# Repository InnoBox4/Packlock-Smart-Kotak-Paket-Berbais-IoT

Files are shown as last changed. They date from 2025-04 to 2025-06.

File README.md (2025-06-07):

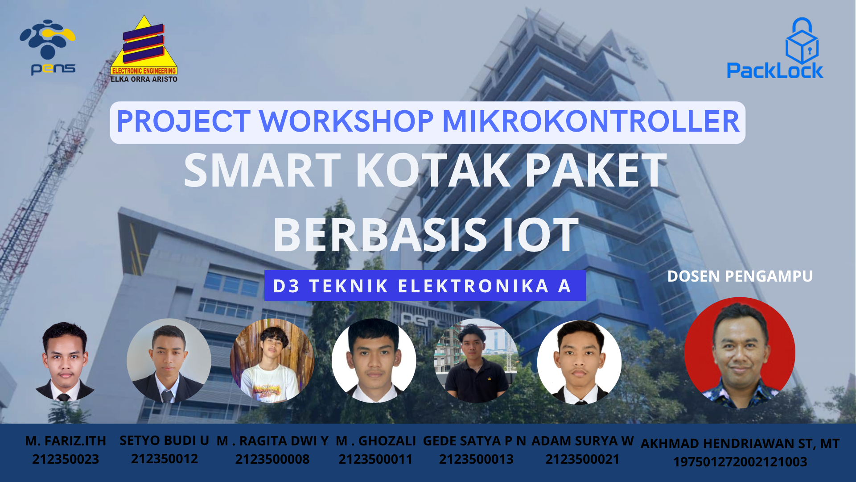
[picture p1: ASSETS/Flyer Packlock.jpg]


# Packlock
## Smart-Kotak-Paket-Berbasis-IoT

Proyek ini bertujuan untuk mengembangkan smart kotak paket berbasis IoT bernama PackLock, yang memungkinkan pengguna memantau status keberadaan paket secara real-time melalui dashboard web berbasis PHP. Sistem ini dirancang sebagai solusi pengiriman barang tanpa tatap muka yang aman dan efisien, terutama di era digital saat ini. PackLock dibangun menggunakan Arduino Uno sebagai mikrokontroler utama yang mengatur pembacaan sensor, kontrol aktuator, dan komunikasi data ke server lokal.

Untuk mendeteksi keberadaan paket, sistem menggunakan sensor infrared yang dipasang di dalam kotak. Selain itu, sensor ultrasonik dan reed switch digunakan untuk memantau status pintu depan dan pintu belakang kotak, apakah dalam keadaan tertutup atau terbuka. Ketika kondisi berubah, sistem akan mengirimkan data ke server melalui komunikasi serial dan hasilnya ditampilkan pada web secara real-time. Pengguna juga dapat menerima notifikasi dan melakukan kontrol jarak jauh melalui dashboard, termasuk membuka pintu kotak secara otomatis.

Web dashboard PackLock dibangun menggunakan PHP yang terhubung ke database untuk menyimpan dan menampilkan status terkini dari kotak paket. Dengan antarmuka yang sederhana, pengguna dapat dengan mudah mengetahui apakah terdapat paket di dalam kotak dan apakah pintu dalam keadaan tertutup atau terbuka. Sistem ini diharapkan dapat meningkatkan keamanan dan efisiensi dalam proses pengiriman dan pengambilan paket di lingkungan rumah atau perkantoran cerdas (smart building).

## Support By :
>- Dosen Pengampu : Akhmad Hendriawan ST., MT. (NIP.197501272002121003)
>- Mata kuliah : Workshop Mikrokontroller
>- Program Studi : D3 Teknik Elektronika
>- Politeknik Elektronika Negeri Surabaya<br>

## Team Member :
| NRP | Nama | Jobdesk |
| :---: | :---: | :---: |
| 2123500023 | Muhammad Fariz Ibnu T.H | Hardware Developer | 
| 2123500011 | M . Ghozali | Mekanik | 
| 2123500013 | Gede Satya Prawira Negara | Programer | 
| 2123500008 | M . Ragita Dwi Yuliansyah | Project Manager (PM) | 
| 2123500012 | Setyo Budi Utomo | Mekanik | 
| 2123500021 | Adam Surya Waskito | UI/UX Designer |

## Komponen Utama 
| Komponen | Fungsi | 
|---|---|
|Arduino Uno| pengontrol sistem |
| Ultrasonic Sensor HC-SR04  | deteksi pintu depan tertutup atau tidak | 
|Sensor Infrared (IR) Proximity FC-51 |deteksi paket masuk|
|Reed Switch + Magnet | deteksi pintu belakang terbuka/tertutup)|
|Servo Motor (SG90 / MG90S)|untuk membuka pintu|

## Flyer Packlock

Flyer Packlock

## Cara kerja Packlock

https://github.com/user-attachments/assets/c9181a2b-23b7-4780-8032-19ebb1beb945

## Iklan Produk Packlock

[Video Iklan Produk Packlock](https://youtube.com/shorts/VkG0_1tyrqw?feature=share)

## PPT Packlock

[PPT Packlock](https://www.canva.com/design/DAGpCFjL8s4/J2JU336eNsQ9mIj8pktKxA/edit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)

## Desain App di Figma

[Desain App Packlock di Figma](https://www.figma.com/design/fq3XM4EmNfqJVly56ajVYE/Packlock?node-id=0-1&t=N5Q5iODnZTlXCq0t-1)

## Desain 3D di Thingiverse 

[Desain 3D di Thingiverse](https://www.thingiverse.com/setyoo_io/collections/43256436/things)

## Simulasi Program di Wokwi

[Simulasi Program di Wokwi](https://wokwi.com/projects/429229658305672193)

## Video Simulasi Program

[Video Simulasi Program](https://github.com/user-attachments/assets/82a5f85e-70d9-47c1-b36e-2be93320dba2)

## Daftar Isi
- [Komponen Yang Digunakan](#Komponen-Yang-Digunakan)
- [Blok Diagram](#Blok-Diagram)
- [Diagram Arsitektur Sistem](#Diagram-Arsitektur-Sistem)
- [Hardware](#Hardware)
- [Desain UI UX](#Desain-UI-UX)
- [Desain 3D](#Desain-3D)
- [Desain Yang Sudah Jadi](#Desain-Yang-Sudah-Jadi)

## Komponen Yang Digunakan
1.Hardware
- Arduino Uno
- Motor Servo
- Sensor IR Obstacle
- Sensor Ultrasonik
- Conector Molex
- Shield PCB
- Kabel Jumper

2.Software
- Arduino IDE
- Visual Studio Code
- Kicad
- Inventor
- Figma
- Wokwi

3.Alat 
- Palu
- Meteran
- Gergaji
- Penggaris
- bulpoint
- Cutter
- Gunting
- Kuas
- Obeng
- Lem Tembak
- Solder 
  
4.Bahan
- Balok kayu Diameter 2 CM (5 Buah)
- Karton
- Paku Kecil
- Lem kayu
- Cat Kayu
- Paku Pines
- Cat putih
- Timah
- Solasi

## Desain Yang Sudah Jadi

Hasil Jadi

## Blok Diagram
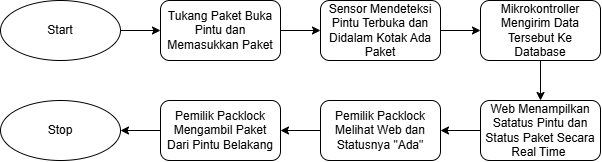
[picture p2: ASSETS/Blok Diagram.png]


## Diagram Arsitektur Sistem
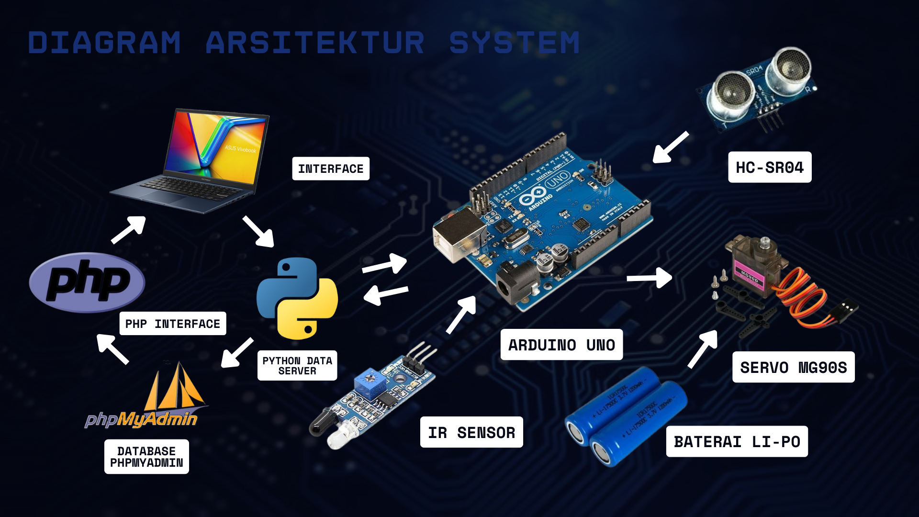
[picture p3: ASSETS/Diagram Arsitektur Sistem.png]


## [Hardware](https://github.com/InnoBox4/Packlock-Smart-Kotak-Paket-Berbais-IoT/tree/main/HARDWARE)

Berikut ini adalah hasil skematik dari rangkaian Smart Kotak Paket Berbasis IoT menggunakan software KiCad.
<div align="center">
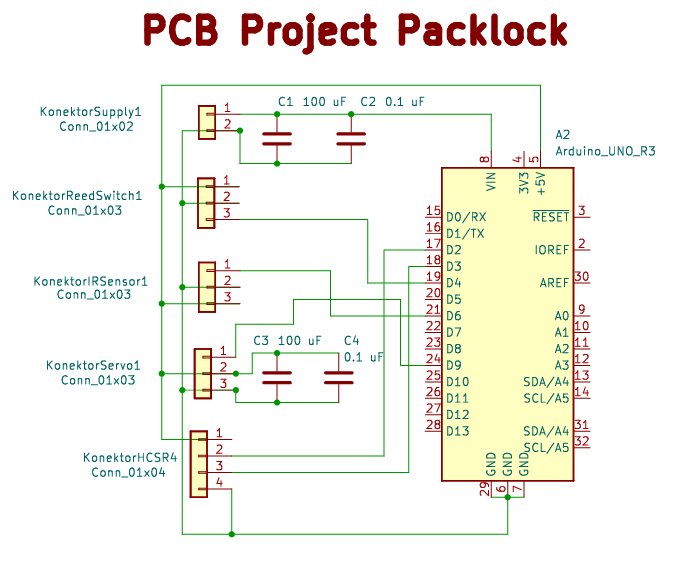
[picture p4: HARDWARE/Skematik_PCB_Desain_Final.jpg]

</div>

Berikut ini adalah hasil layout dari rangkaian Smart Kotak Paket Berbasis IoT menggunakan software KiCad.
<div align="center">
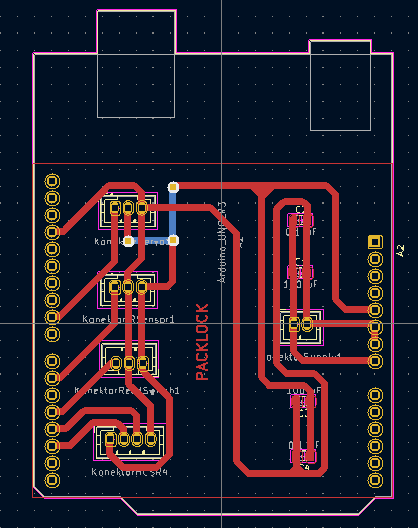
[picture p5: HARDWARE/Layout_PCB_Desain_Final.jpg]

</div>

Berikut ini adalah hasil 3D dari rangkaian Smart Kotak Paket Berbasis IoT menggunakan software KiCad.
<div align="center">
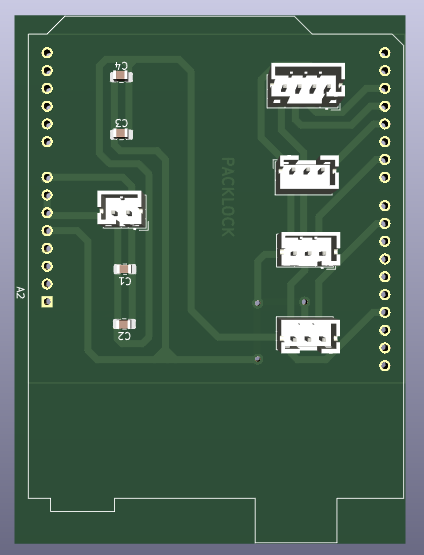
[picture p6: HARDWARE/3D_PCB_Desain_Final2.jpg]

</div>

Berikut ini adalah hasil cetak dari rangkaian Smart Kotak Paket Berbasis IoT menggunakan software KiCad.
<div align="center">
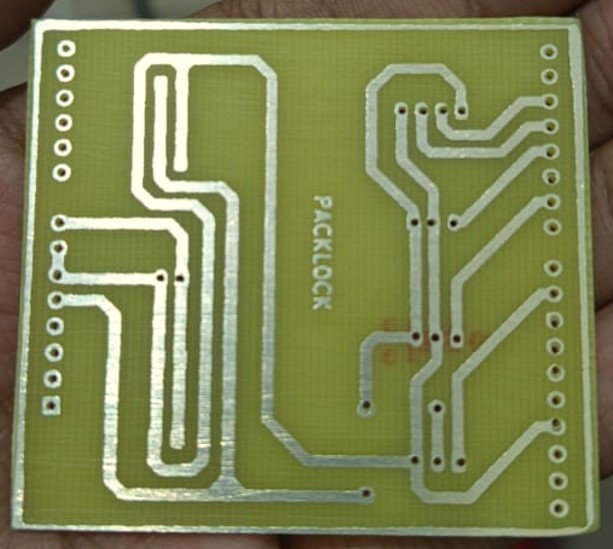
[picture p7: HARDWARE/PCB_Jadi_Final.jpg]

</div>

Berikut ini adalah hardware yang sudah terpasang di Packlock.
<div align="center">
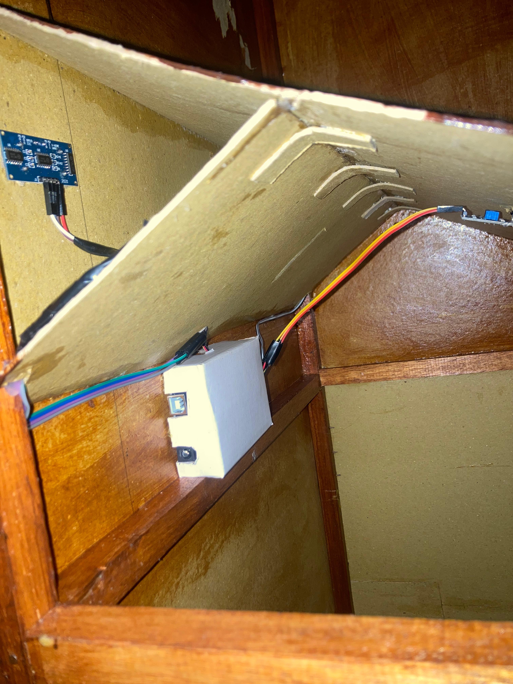
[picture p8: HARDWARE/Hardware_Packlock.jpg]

</div>

## [Desain UI UX](https://github.com/InnoBox4/Packlock-Smart-Kotak-Paket-Berbais-IoT/tree/main/UI-UX)

Berikut ini adalah UI/UX Web Packlock.
<div align="center">
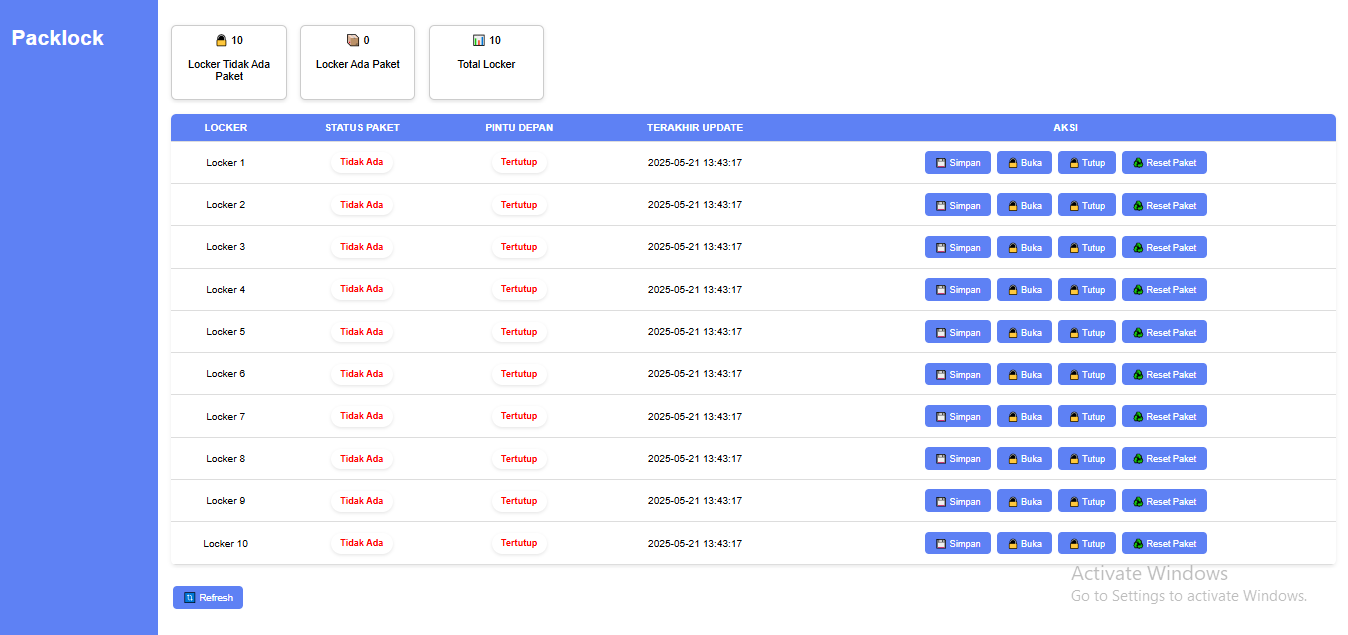
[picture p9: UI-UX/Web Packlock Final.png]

</div>

## [Desain 3D](https://github.com/InnoBox4/Packlock-Smart-Kotak-Paket-Berbais-IoT/tree/main/DESAIN%203D)

Berikut ini adalah Desain 3D Packlock Bagian Dalam.
<div align="center">
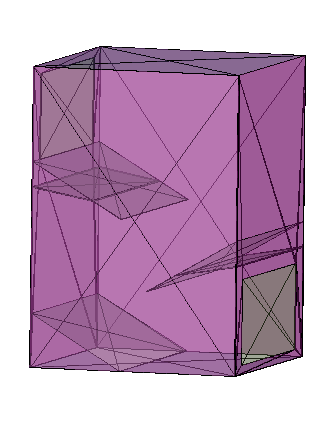
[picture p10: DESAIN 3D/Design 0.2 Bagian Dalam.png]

</div>

Berikut ini adalah Desain 3D Packlock Tampak Depan.
<div align="center">
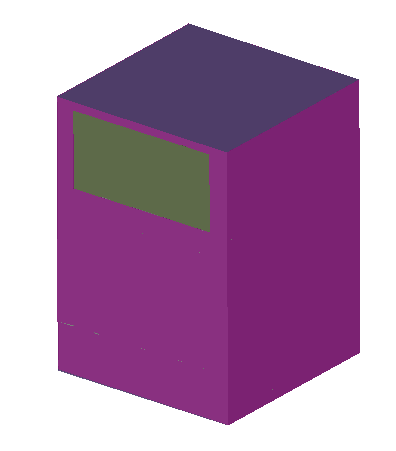
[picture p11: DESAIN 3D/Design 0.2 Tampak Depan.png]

</div>

Berikut ini adalah pembuatan Desain 3D Packlock.

https://github.com/user-attachments/assets/38ecc393-ebad-4563-a7b1-a252cfec6f6e

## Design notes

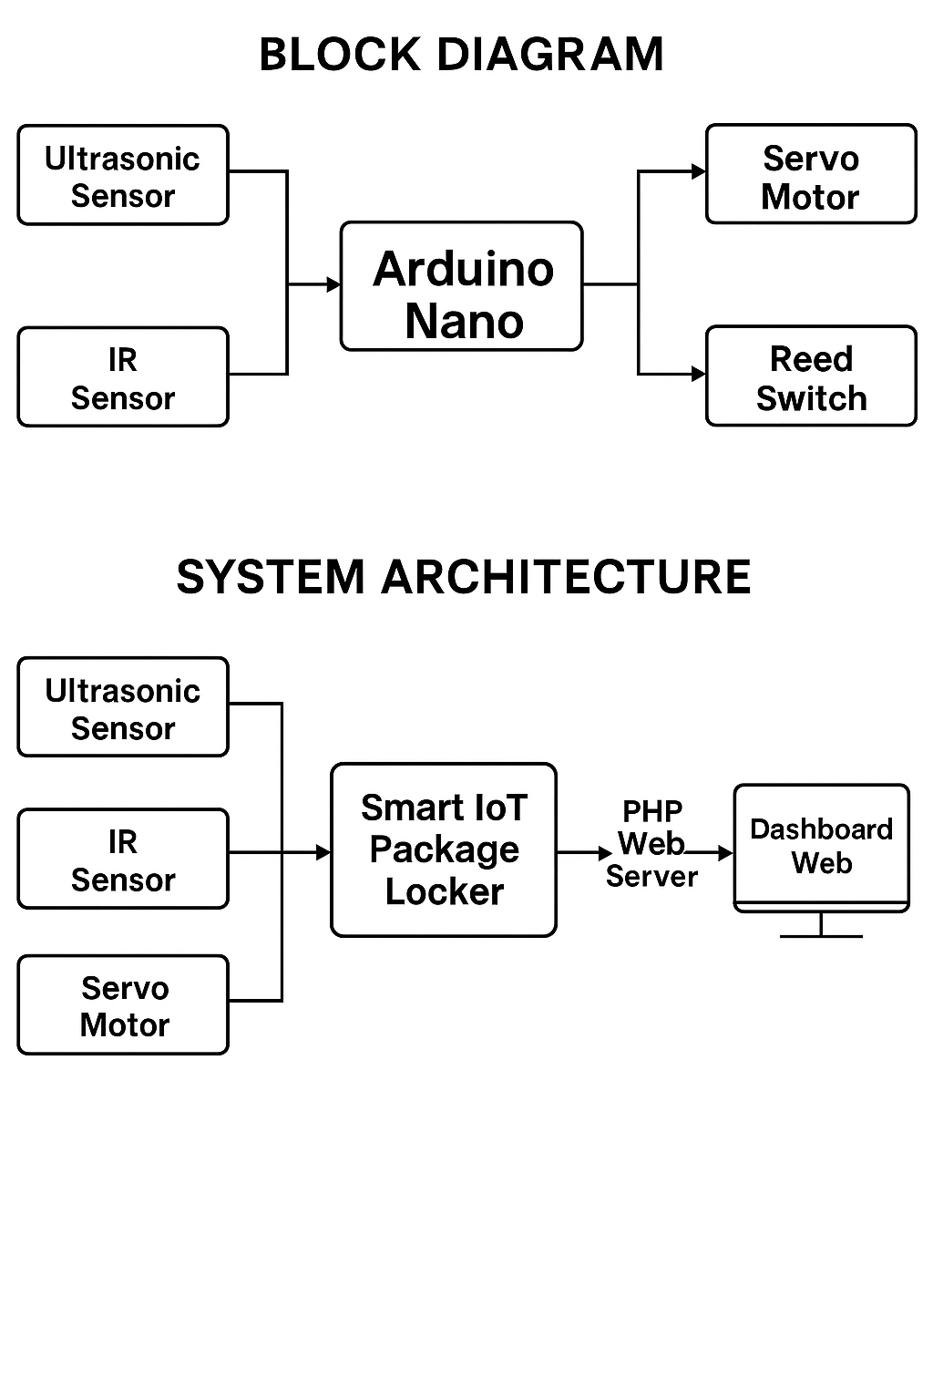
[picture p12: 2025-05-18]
ASSETS/Blok Diagram System Architecture.jpg

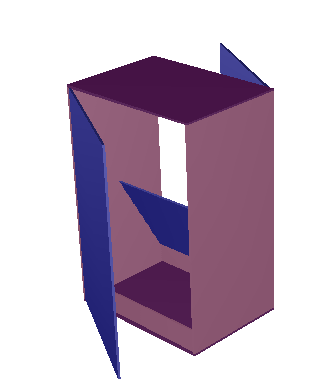
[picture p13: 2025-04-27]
DESAIN 3D/Design 0.1 Tampak Belakang.png

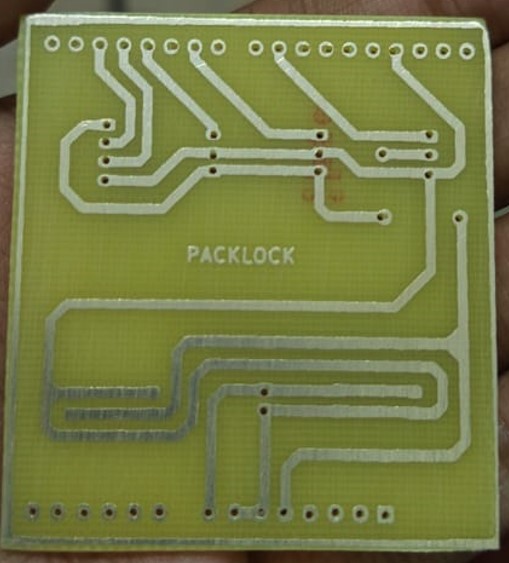
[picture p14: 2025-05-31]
HARDWARE/PCB_Jadi_Final2.jpg

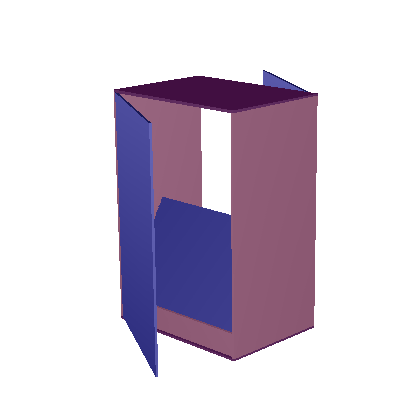
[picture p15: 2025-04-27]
DESAIN 3D/Design 0.1 Tampak Depan.png

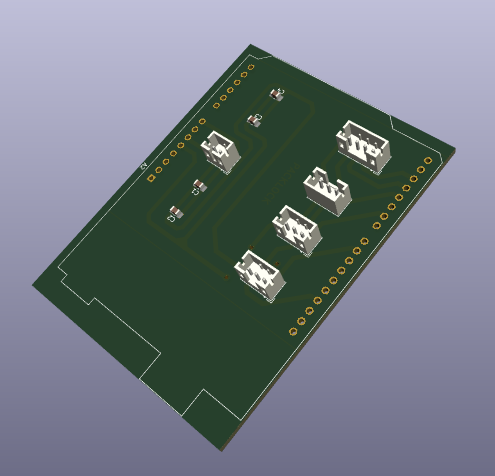
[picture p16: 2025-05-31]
HARDWARE/3D_PCB_Desain_Final.jpg

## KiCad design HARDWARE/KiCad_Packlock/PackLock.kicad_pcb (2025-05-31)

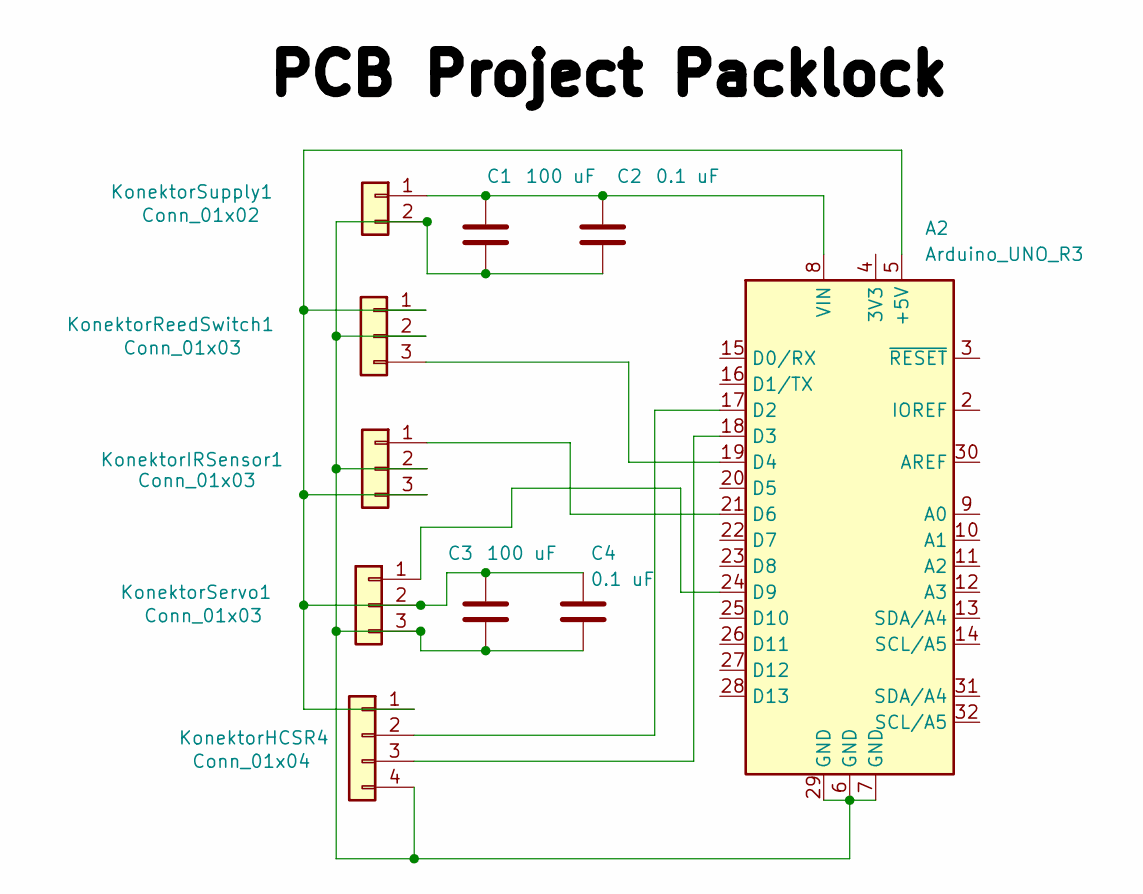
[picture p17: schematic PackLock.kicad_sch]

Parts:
A2: Arduino_UNO_R3
C1, C3: 100 uF; C_0805_2012Metric_Pad1.18x1.45mm_HandSolder
C2, C4: 0.1 uF; C_0805_2012Metric_Pad1.18x1.45mm_HandSolder
KonektorHCSR4: Conn_01x04; JST_PH_B4B-PH-K_1x04_P2.00mm_Vertical
KonektorIRSensor1: Conn_01x03; JST_PH_B3B-PH-K_1x03_P2.00mm_Vertical
KonektorReedSwitch1: Conn_01x03; JST_PH_B3B-PH-K_1x03_P2.00mm_Vertical
KonektorServo1: Conn_01x03; JST_PH_B3B-PH-K_1x03_P2.00mm_Vertical
KonektorSupply1: Conn_01x02; JST_PH_B2B-PH-K_1x02_P2.00mm_Vertical

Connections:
unnamed: A2.5 (+5V), C3.1, C4.1, KonektorHCSR4.1, KonektorIRSensor1.3, KonektorReedSwitch1.1, KonektorServo1.2
unnamed: A2.17 (D2), KonektorHCSR4.2
unnamed: A2.18 (D3), KonektorHCSR4.3
unnamed: A2.19 (D4), KonektorReedSwitch1.3
unnamed: A2.21 (D6), KonektorIRSensor1.1
unnamed: A2.24 (D9), KonektorServo1.1
unnamed: A2.8 (VIN), C1.1, C2.1, KonektorSupply1.1
unnamed: A2.6 (GND), A2.7 (GND), A2.29 (GND), C1.2, C2.2, C3.2, C4.2, KonektorHCSR4.4, KonektorIRSensor1.2, KonektorReedSwitch1.2, KonektorServo1.3, KonektorSupply1.2

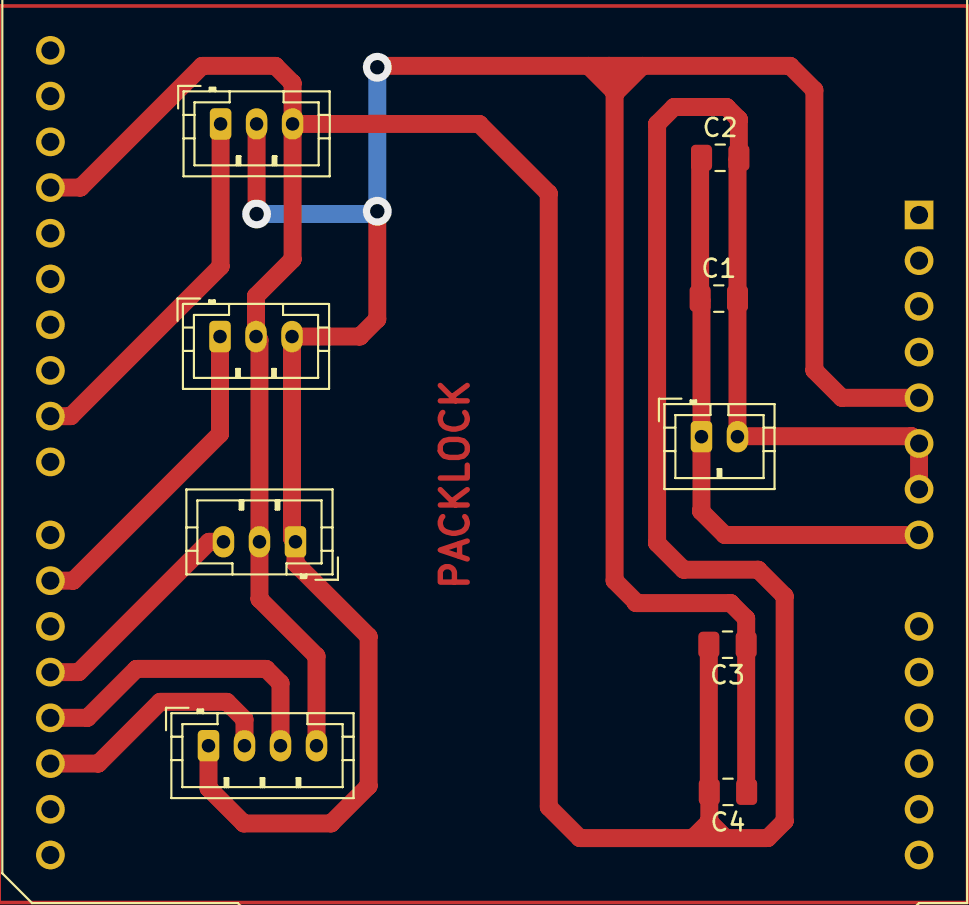
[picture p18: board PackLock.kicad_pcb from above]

Board: 2 copper layers, 10 parts (0 on the bottom side), 8 nets.

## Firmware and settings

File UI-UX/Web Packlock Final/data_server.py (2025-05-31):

import threading
import time
from flask import Flask, request, jsonify
import serial
import requests

app = Flask(__name__)

# Buka serial port Arduino, sesuaikan COM port dan baudrate
try:
    ser = serial.Serial('COM7', 9600, timeout=1)
except serial.SerialException as e:
    print(f"Gagal buka serial port: {e}")
    exit(1)

# Variabel global untuk menyimpan status yang diterima dari Arduino
status_data = {
    "status_paket": None,
    "status_pintu_depan": None,
}

locker_number = 1  # Contoh nomor locker, bisa disesuaikan

# Fungsi background untuk baca data dari Arduino terus menerus
def baca_serial():
    global status_data
    while True:
        try:
            line = ser.readline().decode().strip()
            if line:
                print("[Dari Arduino] >>", line)
                # Parsing format "key=value"
                if "=" in line:
                    key, value = line.split("=", 1)
                    if key in status_data:
                        status_data[key] = value

                # Kalau sudah lengkap data, bisa langsung kirim ke web server lain
                if all(status_data.values()):
                    params = {
                        "locker_number": locker_number,
                        **status_data
                    }
                    print("[Ke PHP] >>", params)
                    try:
                        requests.get("http://localhost/Packlock/update_status.php", params=params, timeout=1)
                    except Exception as e:
                        print(f"Gagal kirim ke PHP: {e}")

        except Exception as e:
            print(f"Error baca serial: {e}")
            time.sleep(1)

# Mulai thread baca serial
threading.Thread(target=baca_serial, daemon=True).start()

# Endpoint Flask untuk menerima perintah dari web dan kirim ke Arduino
@app.route('/send_command', methods=['GET', 'POST'])
def send_command():
    aksi = request.args.get('aksi') or request.form.get('aksi')
    if not aksi:
        return jsonify({"success": False, "error": "Parameter 'aksi' dibutuhkan"})

    # Perlakuan khusus jika perintah adalah reset_paket
    if aksi == "reset_paket":
        status_data["status_paket"] = "Tidak Ada"
        print("[Reset Lokal] >> status_paket di-set ke 'Tidak Ada' secara lokal")

    try:
        # Tetap kirim perintah ke Arduino lewat serial
        ser.write((aksi + '\n').encode())
        print(f"[Ke Arduino] >> {aksi}")
    except Exception as e:
        return jsonify({"success": False, "error": f"Gagal kirim ke Arduino: {e}"})

    return jsonify({"success": True, "message": f"Perintah '{aksi}' berhasil dikirim ke Arduino"})

if __name__ == '__main__':
    # Jalankan Flask server
    app.run(host='0.0.0.0', port=5000)

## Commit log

2025-04-27 Create PCB_Desain
2025-05-31 Update and rename HARDWARE/PackLock2.kicad_pcb to HARDWARE/KiCad_Packlock/PackLock.kicad_pcb
    [PackLock.kicad_pcb]
2025-05-31 Update and rename HARDWARE/PackLock2.kicad_sch to HARDWARE/KiCad_Packlock/PackLock.kicad_sch
    [PackLock.kicad_sch]
2025-05-31 Update and rename UI-UX/arduino_server.py to UI-UX/Web Packlock Final/data_server.py
